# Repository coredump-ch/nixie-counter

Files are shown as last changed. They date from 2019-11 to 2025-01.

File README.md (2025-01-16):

# Nixie Counter

## Description / Overview

PCB for a physical "people now present" counter that sends it data directly to
the [SpaceAPI](https://spaceapi.io/).

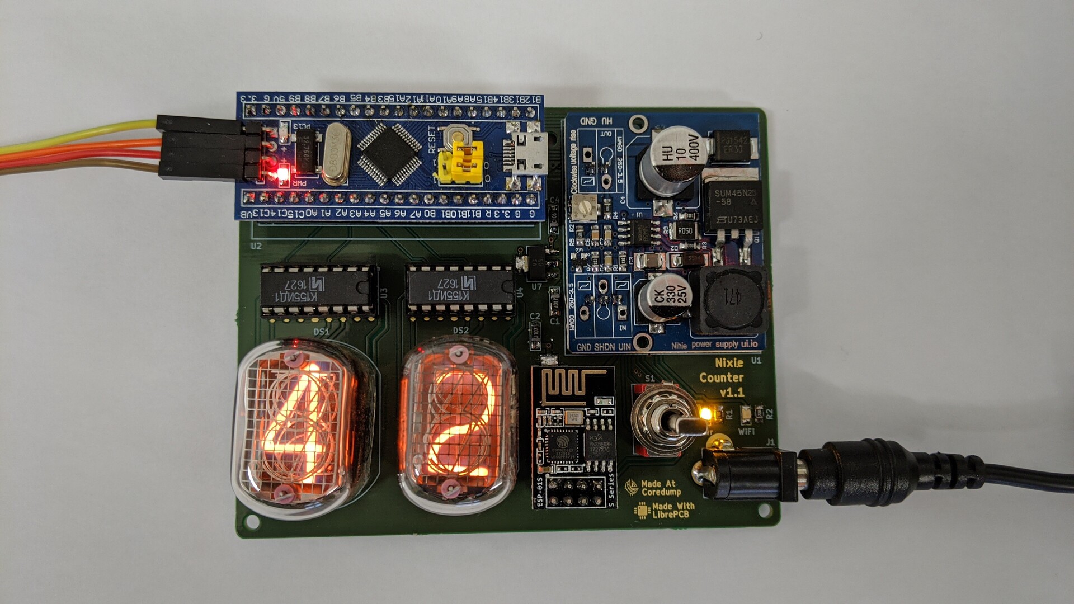
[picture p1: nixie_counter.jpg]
Photo without enclosure


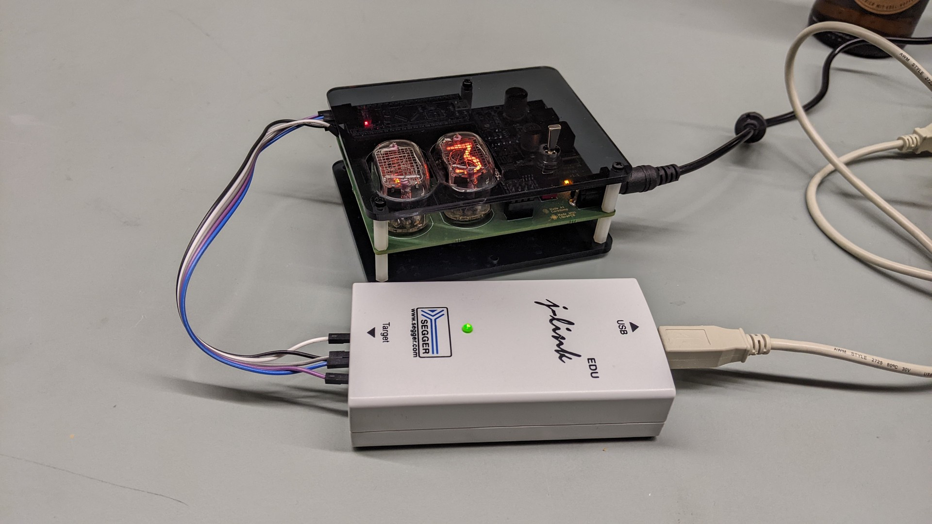
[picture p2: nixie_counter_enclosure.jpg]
Photo with enclosure


**Microcontroller**

The microcontroller is an ESP32C3 based [M5Stack
STAMP-C3U](https://docs.m5stack.com/en/core/stamp_c3u) board. We chose this
because it's quite cheap, has everything built-in that we need and it can run
firmware written in [Rust](https://www.rust-lang.org/).

**Input Methods**

To enter the number of people present, a 2-position momentary toggle switch is
used that can be pushed upwards or downwards.

**Display**

The number of people present is then displayed on two IN-12B nixie tubes. Those
tubes need 150-160 V for turning on, for this we use a [NCH6100HV
module](https://www.nixie.ai/nch6100hv/). The tubes are controlled through two
K155ID1 BCD-to-Decimal drivers. Those need 5V logic levels, so we use a level
shifter between the drivers and the microcontroller.

**Power Supply**

Input power is supplied at 12V. The nixie power supply converts that to ~150V.

An LDOs convert the 12V to 5V, for both the nixie drivers and the ESP32 module.

**Status LEDs**

There's a yellow LED to indicate that the controller has power and runs the
correct firmware, and a green LED to indicate whether the module is connected
to the WiFi or not.

## Functionality

- When starting, the people count will be set to 0
- When pressing the toggle switch up or down, the people count will be modified
  and the nixie tube will show the sent number
- Every minute, the current count will be re-sent to the server (to allow
  server-side timeout implementations)

## PCB

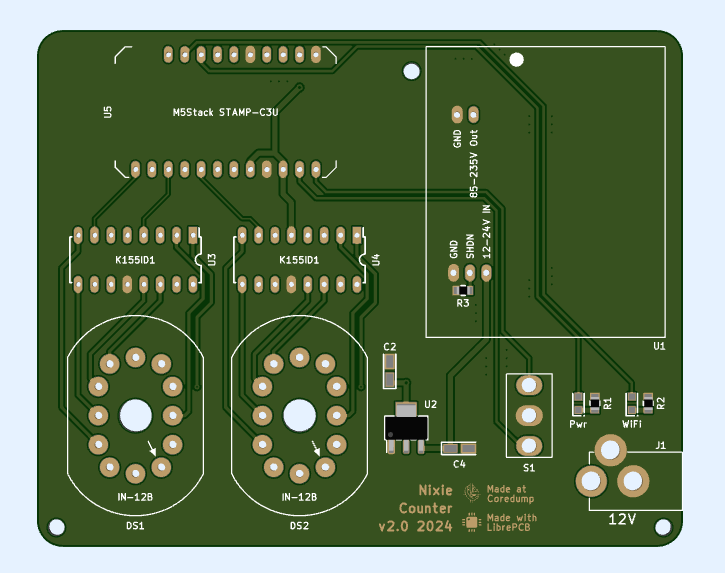
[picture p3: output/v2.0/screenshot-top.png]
Top


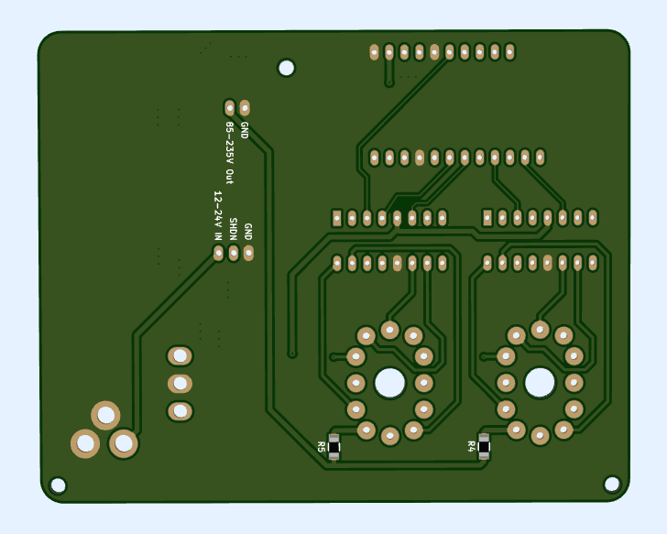
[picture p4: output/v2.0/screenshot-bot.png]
Bottom


For the BOM, see
[`output/v2.0/assembly/Nixie_Counter_v2.0_BOM_Std.csv`](output/v2.0/assembly/Nixie_Counter_v2.0_BOM_Std.csv)
and
[`output/v2.0/assembly/Nixie_Counter_v2.0_BOM_Std.html`](output/v2.0/assembly/Nixie_Counter_v2.0_BOM_Std.html).

## Editing

This is a [LibrePCB](https://librepcb.org) project!

## License

TAPR Open Hardware License, see [LICENSE.txt](LICENSE.txt).

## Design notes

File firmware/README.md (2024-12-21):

# Nixie Counter Firmware

## Prerequisites

- Rust
- Cargo
- espflash
- ldproxy

## Flashing

    export WIFI_SSID=...
    export WIFI_PASS=...
    export SPACEAPI_SENSOR_ENDPOINT=http://example.com/sensors/people_now_present/
    cargo run --release

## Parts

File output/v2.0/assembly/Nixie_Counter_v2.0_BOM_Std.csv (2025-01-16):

Quantity | Designators | Package | SOURCE | ALIEXPRESS | DIGIKEY | Value | MPN | Manufacturer | Value[2] | MPN[2] | Manufacturer[2]
1 | C2 | CAPPM320X160X180L80X120 |  |  | 478-8152-1-ND | 100μF | F930J107KAA | AVX
1 | C4 | CAPPM320X160X180L80X120 |  |  | 478-8237-1-ND | 10μF | F931C106MAA | AVX
2 | DS1, DS2 | Reflektor / Sovtek IN-12 | Ebay |  |  |  | IN-12B | Reflektor
1 | J1 | Barrel Jack DC-005 |  |  |  | Barrel Jack Center Pos
1 | L1 | LOGO_COREDUMP_3.4mm |  |  |  | Made at Coredump
1 | LED1 | OSRAM_CHIPLED0805_DIFFUSED |  |  | 475-2560-1-ND | Pwr | LY R976-PS-36 | OSRAM
1 | LED2 | OSRAM_CHIPLED0805_DIFFUSED |  |  | 475-1410-1-ND | WiFi | LG R971-KN-1 | OSRAM
1 | R1 | RESC2012 (0805) |  |  | 311-270CRCT-ND | 270Ω | RC0805FR-07270RL | Yageo
1 | R2 | RESC2012 (0805) |  |  | 311-220CRCT-ND | 220Ω | RC0805FR-07220RL | Yageo
1 | R3 | RESC2012 (0805) |  |  | 311-0.0ARCT-ND | 0Ω | RC0805JR-070RL | Yageo
2 | R4, R5 | RESC3216 (1206) |  |  | 311-15.0KFRCT-ND | 15kΩ | RC1206FR-0715KL | Yageo
1 | S1 | Salecom T8014A-UHBx | AliExpress | https://aliexpress.com/item/33033590581.html |  |  | T8014A-UHBx | Salecom
1 | U1 | NCH6100HV | AliExpress | https://aliexpress.com/item/32834903717.html |  | NCH6100HV Power Supply
1 | U2 | SOT223-4P230_700X180L175X75T175X300 |  |  | 296-21114-1-ND | LDO 5V | TLV1117-50CDCYR | Texas Instruments
2 | U3, U4 | DIP762W55P254L2007H533Q16 | Ebay |  |  |  | К155ИД1 | Integral
1 | U5 | M5STACK_STAMP_C3U |  |  |  |  | K122 | M5Stack |  | C122-B | M5Stack

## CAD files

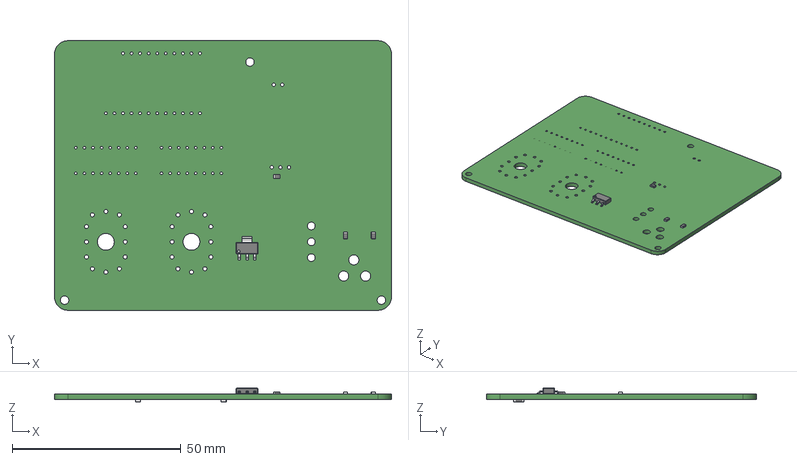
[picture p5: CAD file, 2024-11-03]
output/v2.0/Nixie_Counter_v2.0.step
100.0 x 80.0 x 4.10 mm
PCB:1
R1:1
R2:1
R3:1
R4:1
R5:1
U2:1

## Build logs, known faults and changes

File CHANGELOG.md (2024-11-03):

# Hardware Changelog

## v2.0

- Switch to ESP32C3 based board, redesign whole PCB
- Remove ESP8266 module (not needed anymore)
- Remove 3.3V LDO (not needed anymore)
- Add text and frames to schematic

## v1.1

- Add tube anode resistor
- Flip nixie tube footprint (it was on the wrong side)
- Rounded corners
- Improve label placement

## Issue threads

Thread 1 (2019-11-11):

Power supply for blue pill

dbrgn, 2019-11-11:
It would be nice if we could avoid having to power the blue pill through USB.

Maybe re-use the adjustable regulator board from the iC880A backplane project.

dbrgn, 2019-11-15:
Argh, it gets a bit complicated.

I first added a 3.3V 800mA LDO for the Blue Pill and the ESP8266, but then realized that the 5V output of the Blue Pill (required for the logic level of the BCD chips) does not work when not plugged in via USB.

I then replaced the LDO with a 5V version, in order to power the Blue Pill through that LDO directly. The issue now is that the regulator on the Blue Pill will only output 300 mA. For the ESP8266, it is recommended to be able to provide at least 300 mA continuously, but it would have to share that with the Blue Pill.

It's all less than ideal... We could of course add two LDOs, one for 5V and one for 3.3V, both powered by the 12V PSU.

Alternatively, we drop the blue pill completely (it *is* overkill) and use something like an ESP8266 or ESP32, but with the firmware written in C instead of Rust. This would probably be the most pragmatic approach.

What do you think, @rnestler?

dbrgn, 2019-11-21:
For the record, I'll simply add a second LDO.

Closed 2019-11-23.

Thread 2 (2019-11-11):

Add Logos to board

dbrgn, 2019-11-11:

dbrgn, 2019-11-24:
LibrePCB logo missing, see #7.

Closed 2019-11-24.

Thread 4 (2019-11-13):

Add ESP8266

dbrgn, 2019-11-13:

rnestler, 2019-11-13:
Huh you want an ESP8266 *and* the bluepill?

dbrgn, 2019-11-13:
The blue pill does not have any networking. How do you transmit the data to the internet? :slightly_smiling_face:

(Blue pill, 'cause Rust :crab: I think native ESP8266 support still isn't that good. I'd use the ESP as a serial modem.)

rnestler, 2019-11-13:
Why not just use an nRF module then? https://www.nordicsemi.com/Products/Low-power-short-range-wireless They have good Rust support and have WiFi as well, right?

dbrgn, 2019-11-13:
There are a few WiFi modules with Rust support, but no drivers for the WiFi stack...

Here would be 2 experimental crates for ESP8266 over serial support:

- https://github.com/TheZoq2/esp01-rs
- https://github.com/laanwj/k210-sdk-stuff/tree/master/util/esp8266at

An alternative would be the RTL8710, but I doubt that the software support is better...

Ideally we'd have a native Rust WiFi driver for one of those boards.

Closed 2019-11-23.

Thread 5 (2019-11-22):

Turning on NCH6100HV with Blue Pill

dbrgn, 2019-11-22:
Should the power supply for the nixie tubes be connected to the blue pill so we can turn it on and off with a GPIO?

When pulling SHDN pin high, the power supply turns off.

Rationale: When the power supply is off by default, we can initialize everything (including WiFi) before turning on the tubes.

Requirements: The GPIO pin would need to be high at boot, otherwise this would be of little use.

dbrgn, 2019-11-23:
As far as [I can tell](https://electronics.stackexchange.com/questions/28531/what-is-the-common-pin-configuration-upon-microcontroller-reset) the GPIO pins are configured as inputs after reset, which means that the tube power supply would get power for a few milliseconds before we can turn it off. So this would be of little use if we want to control the power draw when powering on.

While the power supply would run when SHDN is connected directly to GND (or left floating), the tubes are off by default, so I don't think this is a big issue.

Closed 2019-11-23.

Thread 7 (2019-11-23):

Review

dbrgn, 2019-11-23:
@rnestler @ubruhin Does one of you have time to give this board a review? I think it should now be ready for ordering a prototype PCB.

For an overview, see the README file.

ubruhin, 2019-11-24:
I didn't review it in detail, but some mounting holes in the PCB might be nice to have :)

And the "Made With LibrePCB" logo is missing :scream:

dbrgn, 2019-11-24:
Oh, two very good points :smile:

dbrgn, 2019-11-24:
Both fixed.

Closed 2019-11-29.

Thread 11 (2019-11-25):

Increase clearance for 150V traces

dbrgn, 2019-11-25:
0.4 or 0.5mm

dbrgn, 2019-11-26:
Changed to 0.45mm.

Closed 2019-11-26.

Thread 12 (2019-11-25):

Change footprint of toggle switch

dbrgn, 2019-11-25:
Directly solder in the switch. Verify that height is OK.

dbrgn, 2019-11-26:
Should work if we leave 20mm space inside the enclosure!

Closed 2019-11-29.

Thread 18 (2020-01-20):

Add resistor for the Tubes

rnestler, 2020-01-20:
@dbrgn Did you already do this?

dbrgn, 2020-01-20:
Yes, but I haven't pushed it yet. I first want to solder in a resistor manually to test whether it works as intended. If that's the case, I'll probably order new PCBs.

dbrgn, 2020-02-03:
Fixed in 6192590d353f609020a5828986d185787f941594

Closed 2020-02-03.

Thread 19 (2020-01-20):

v1.0 Testing: Verify that nixie tubes work

dbrgn, 2020-01-20:
Main issue found: Missing anode resistor for tubes. #18

dbrgn, 2020-02-03:
Also, the footprint is mirrored (top/down) :man_facepalming:

Closed 2020-02-25.

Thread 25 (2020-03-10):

WiFi

dbrgn, 2020-03-10:
Create a ESP8266 WiFi driver and send counter changes to the SpaceAPI.

Make sure to show/hide the WiFi LED when the connection status changes. Blink it when sending data.

dbrgn, 2023-10-16:
Obsolete. Replace with ESP32 which is much more reliable.

Closed 2023-10-16.

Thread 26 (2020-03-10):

Sleep when idle

dbrgn, 2020-03-10:
Wake up on interrupt.

May have implications on WiFi module (#25).

dbrgn, 2024-12-20:
This should be automatically the case with embassy (see #41).

Closed 2024-12-20.

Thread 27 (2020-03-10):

Create enclosure

dbrgn, 2020-03-10:
Rough idea: Use laser cut acrylic top plate, connected to the PCB using spacers.

I'm not yet sure about the back side yet...

dbrgn, 2023-10-16:
Completed in a0179ab

Closed 2023-10-16.

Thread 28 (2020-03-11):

Expose PB3 (ITM SWO)

dbrgn, 2020-03-11:
Unfortunately, pin PB3 is currently connected to the power LED, even though this pin would be required for logging through ITM.

Free and expose the ITM pin for easier debugging.

dbrgn, 2024-10-27:
Obsolete with ESP32.

Closed 2024-10-27.

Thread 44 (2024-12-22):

NCH6100HV: Larger holes

dbrgn, 2024-12-22:
The holes are too small.

dbrgn, 2024-12-22:
Hmm, holes are already 1mm in the PCB design. Is that not enough?

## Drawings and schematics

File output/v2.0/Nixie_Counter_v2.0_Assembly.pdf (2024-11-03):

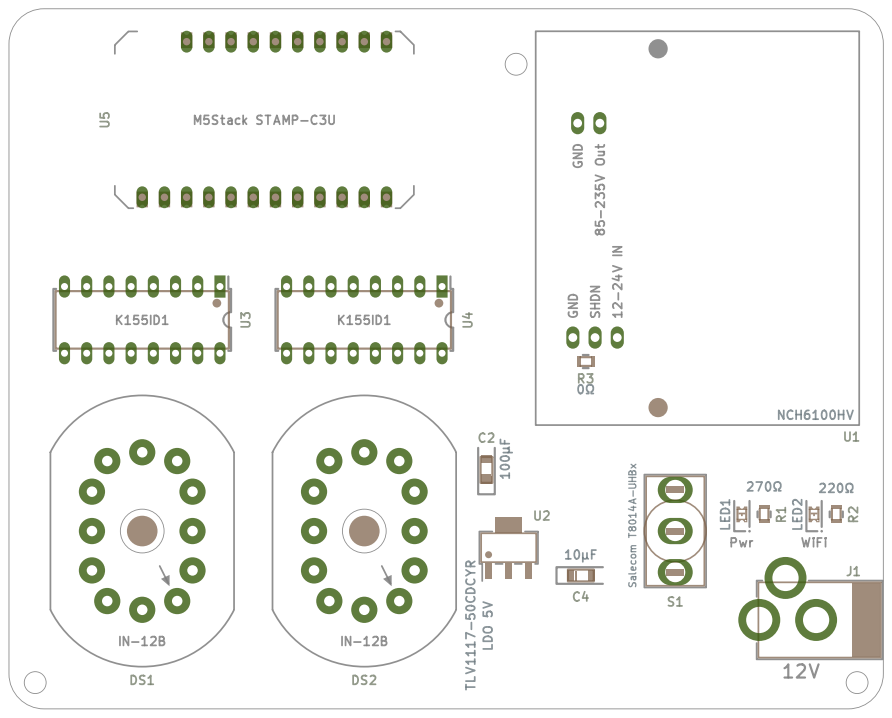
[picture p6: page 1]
85-235V Out; LDO 5V; Salecom T8014A-UHBx

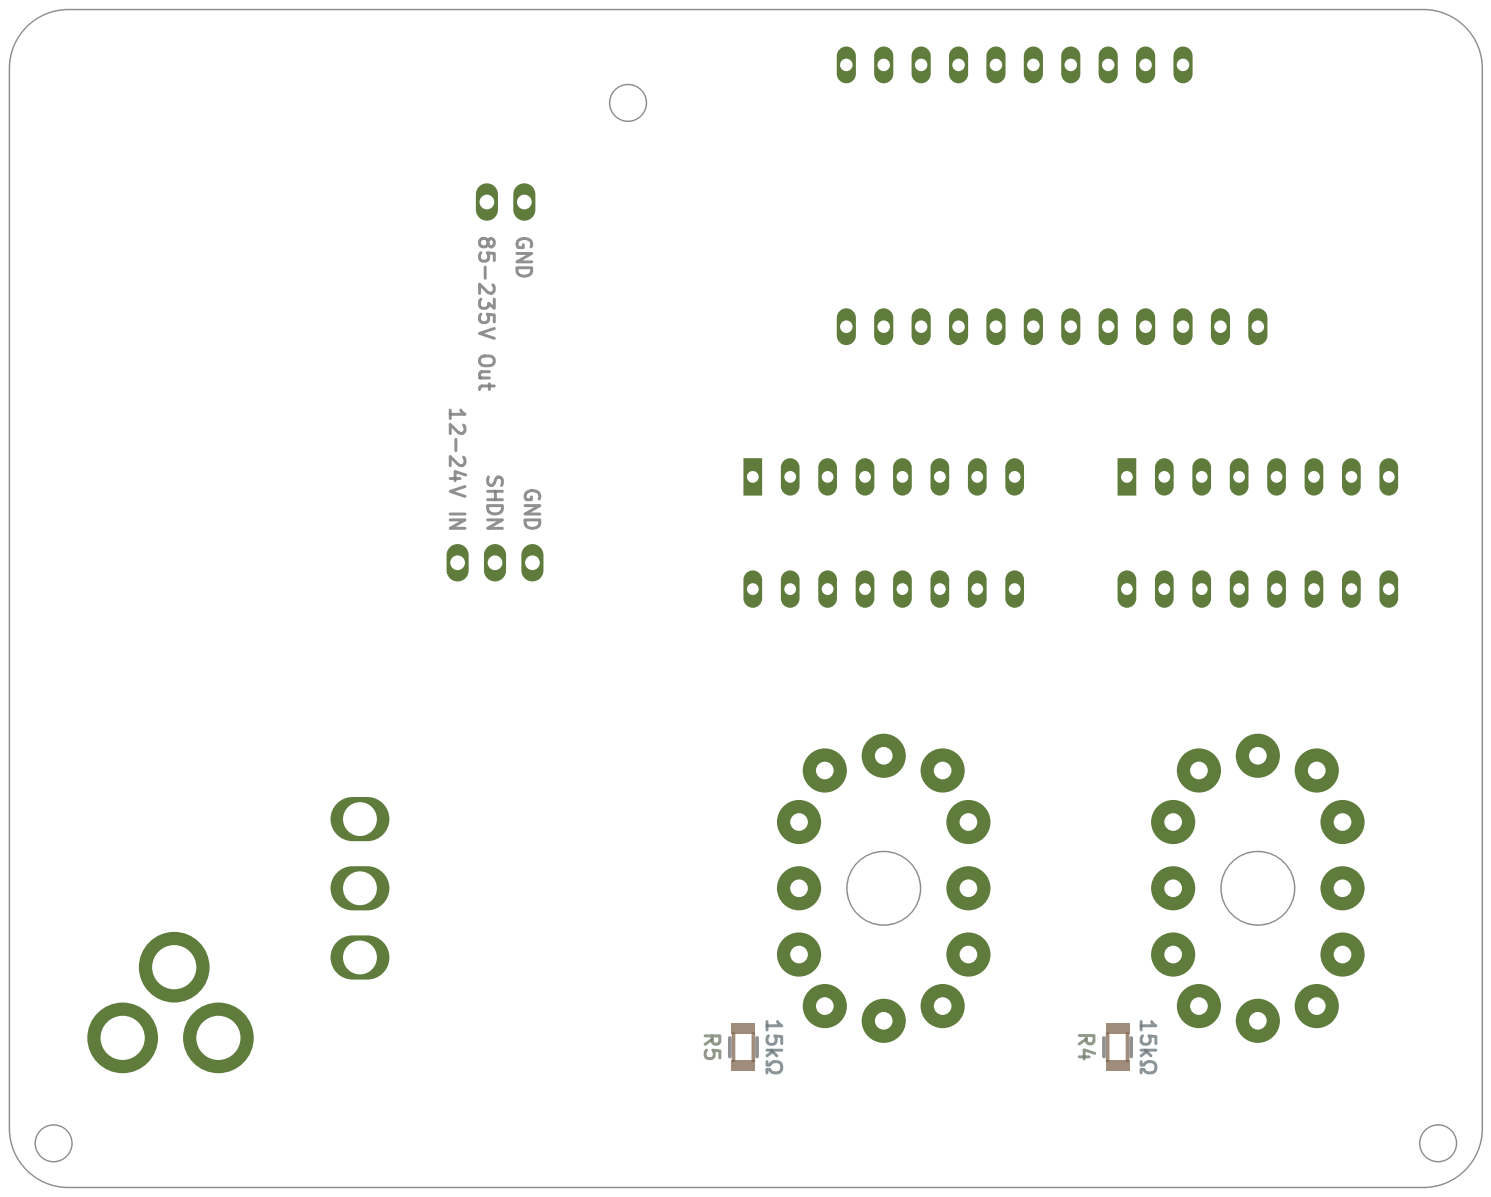
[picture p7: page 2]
85-235V Out

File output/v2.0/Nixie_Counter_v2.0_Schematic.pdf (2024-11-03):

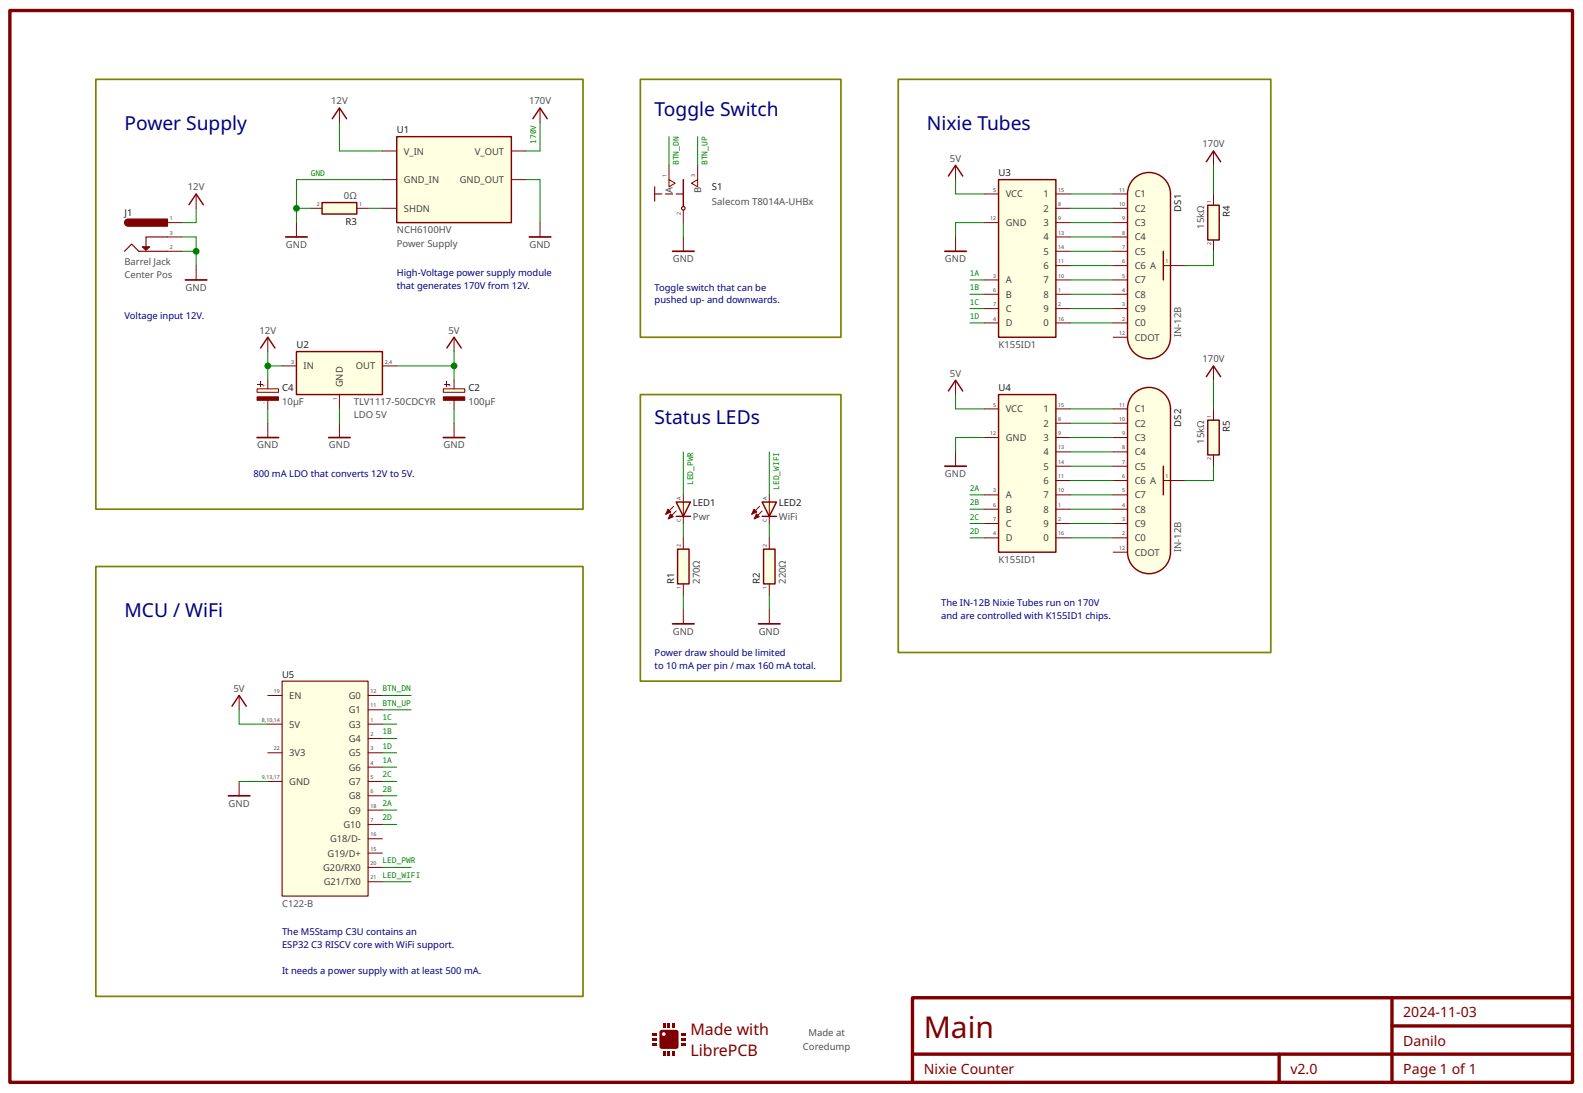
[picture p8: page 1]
GND 1; WiFi LED2; nilo in; V. Nixie; al. MCU / WiFi; The M5Stamp C3U contains an ESP32 C3 RISCV core with WiFi support. It needs a power supply with at least 500 mA.; 2A ED_WIFI

s. Power draw should be limite

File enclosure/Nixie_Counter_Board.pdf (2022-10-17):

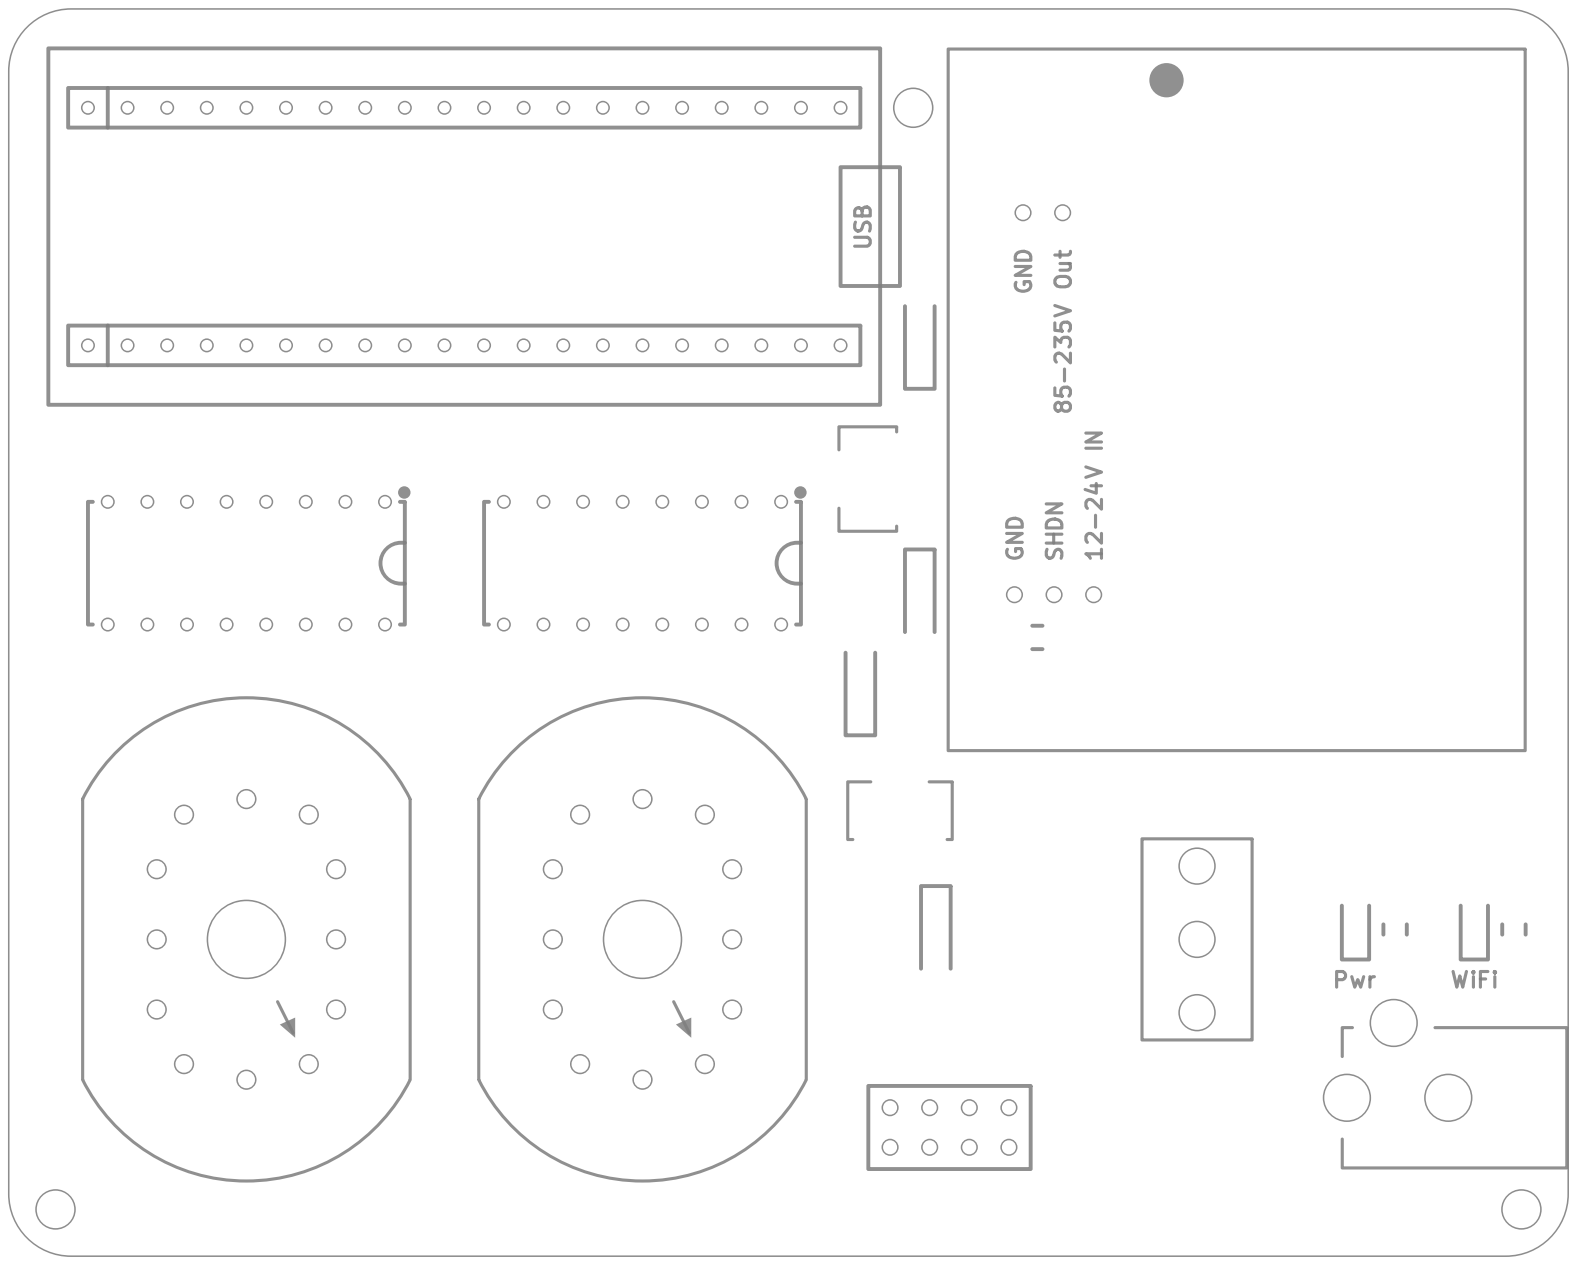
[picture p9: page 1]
85-235V Out

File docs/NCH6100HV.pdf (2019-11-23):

NCH6100HV High Voltage Power Supply v1.0.0 | http://www.nixieclock.org
Designer: Yan Zeyuan. China. | Email:yanzeyuan@163.com | Website：www.nixieclock.org | 1 / 4

# NCH6100HV High Voltage DC Power Supply

Designer： | Yan Zeyuan | Version 1.0.0
Website： | http://www.nixieclock.org
E-mail： | yanzeyuan@163.com

# Attention

### ◇ Attention： High voltage circuit on the board, do not touch the circuit board and

| components if it’s working.
◇ Warning: | Overload prohibited (Input voltage/output current out of range).
◇ Warning: | Exposing outdoor prohibited, using in moist or raining place prohibited.
◇ Warning: | Board will generate heat, be sure the board is well heat dissipation.

# Features

### NCH6100HV high voltage power supply module is miniature step-up DC-DC converter with high

efficiency and low heat operating from 12 to 24VDC input, with an output of 85 to 235VDC set by a precise potentiometer. Designed for Nixie tube, VFD tube, Magic eye etc. Shutdown mode are controlled via SHDN logic input. PCB terminals and pin headers are optional.

# Technical specifications

### Electronic Specifications

Specification | Symbol | Min | Typ | Max | Units
Input voltage | VIN | 10.00 | 12.00 | 24.00 | Volts
Output voltage (Io = 10mA) | VOUT | 85.00 | --- | 235.00 | Volts
Output current (VIN = 12V VOUT = 90V) | IOUT | 0 | 45 | 95 | mAmps
Output current (VIN = 12V VOUT = 170V) | | 0 | 35 | 55 | mAmps
Output current (VIN = 12V VOUT = 220V) | | 0 | 24 | 35 | mAmps
SHDN input voltage | VSHDN | 1.2 | --- | VIN | Volts
SHDN input current | ISHDN | --- | --- | 2 | mAmps
Shutdown current (VIN = 12V VOUT = 170V) | IOFF | --- | 15 | --- | mAmps
Efficiency (VIN = 12-18VDC, 50%-80% rated load) | Efficiency | --- | 80 | --- | %

Notes:

1. Ground or float SHDN to enable switcher, must be tied to VIN to turn off switcher.
2. No input reverse polarity protection is provided.

Designer: Yan Zeyuan. China. | Email:yanzeyuan@163.com | Website：www.nixieclock.org | 2 / 4

### Efficiency curve ( VIN = DC 12V )

### Typical connection

95

90

85

80

75

70

Efficiency - %

0 | 40 | 60 | 80 | 100
Ouput current - mA

Vo = 90v

EFFICIENCY
vs
OUTPUT CURRENT

20

95

90

85

80

75

70

Efficiency - %

0 | 10 | 20 | 30 | 40 | 50 | 60 | 70
Ouput current - mA

Vo = 170v

EFFICIENCY
vs
OUTPUT CURRENT

95

90

85

80

75

70

Efficiency - %

0 | 10 | 20 | 30 | 40
Ouput current - mA

Vo = 220v

EFFICIENCY
vs
OUTPUT CURRENT

DC 12v - 24v IN

GND | GND

SHDN

VIN

GND

HV | DC 85v - 235v OUT

GND

NCH6100HV

DC 12v - 24v IN

GND | GND

SHDN
VIN

GND

HV | DC 85v - 235v OUT

GND

NCH6100HV

DC 12v - 24v IN

GND | GND

SHDN

VIN

GND

HV | OUT OFF

GND

NCH6100HV

DC 12v - 24v IN

GND | GND

SHDN
VIN

GND

HV | OUT ON/OFF

GND

NCH6100HV

I/O | MCU | GND | GND

Always on - float SHDN

ON with connect SHDN to GND

Off with connect SHDN to VIN

MCU control
SHDN High - Off
SHDN Low - On

Note:

### 1. Recommended input capacitor if the module is located far

from the power.

### 2. Module will generate heat, be sure the board is well heat

dissipation.

### Adjust output voltage

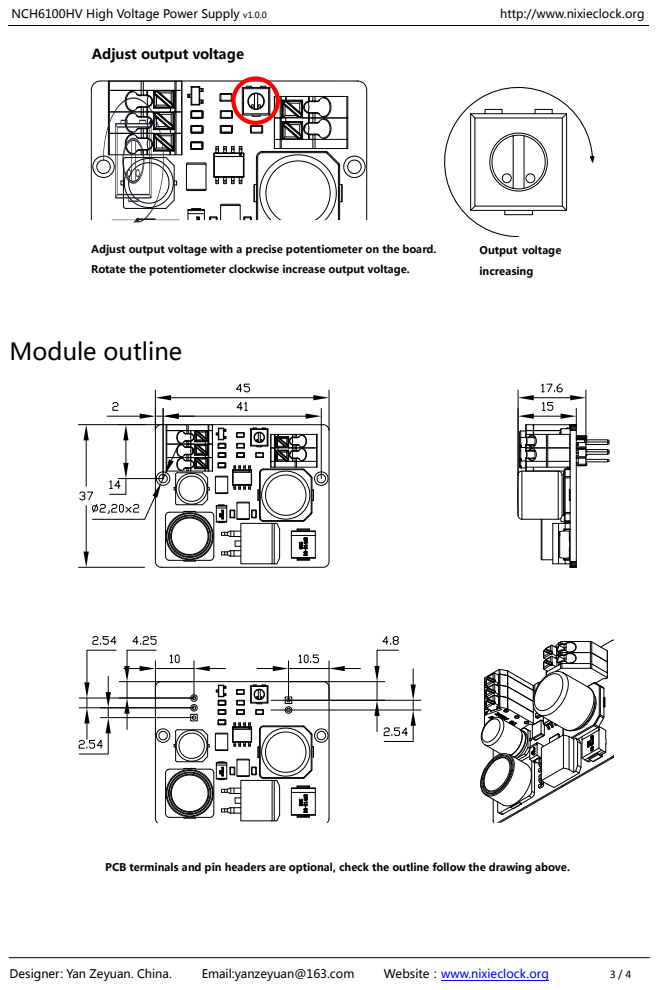
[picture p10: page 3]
Designer: Yan Zeyuan. China.; Email:yanzeyuan@163.com; Website：www.nixieclock.org; Module outline; Output voltage; increasing

Adjust output voltage with a precise potentiometer on the board.
Rotate the potentiometer clockwise increase output voltage.

PCB terminals and pin headers are optional, check the outline follow the drawing above.

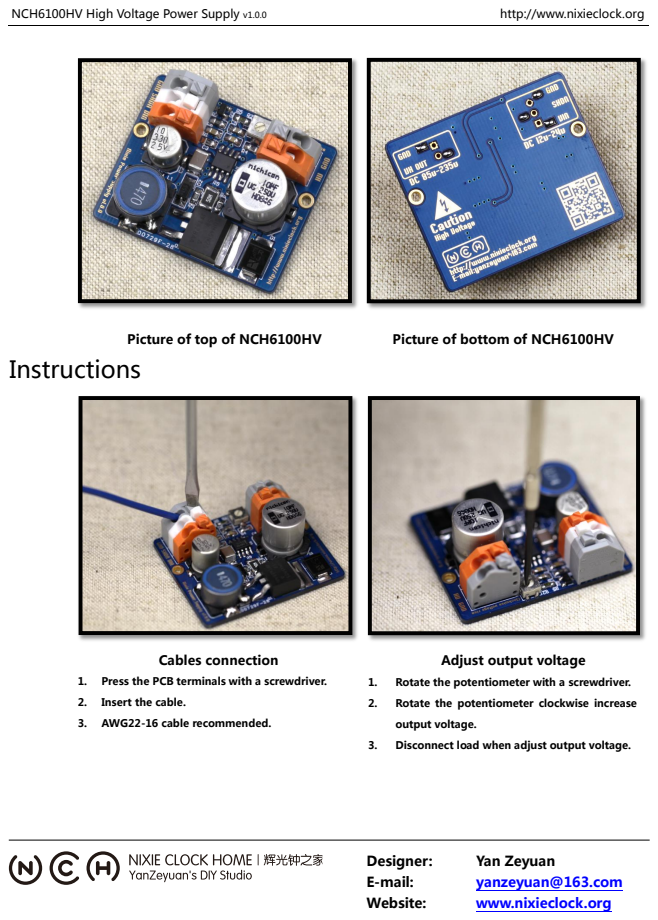
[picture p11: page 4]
Designer: Yan Zeyuan. China.; Email:yanzeyuan@163.com; Website：www.nixieclock.org; Picture of top of NCH6100HV; Picture of bottom of NCH6100HV; Instructions; Designer:; Yan Zeyuan; E-mail:; yanzeyuan@163.com; Website:; www.nixieclock.org; Cables connection

Adjust output voltage

1. Press the PCB terminals with a screwdriver.
2. Insert the cable.
3. AWG22-16 cable recommended.

1. Rotate the potentiometer with a screwdriver.
2. Rotate the potentiometer clockwise increase
output voltage.
3. Disconnect load when adjust output voltage.

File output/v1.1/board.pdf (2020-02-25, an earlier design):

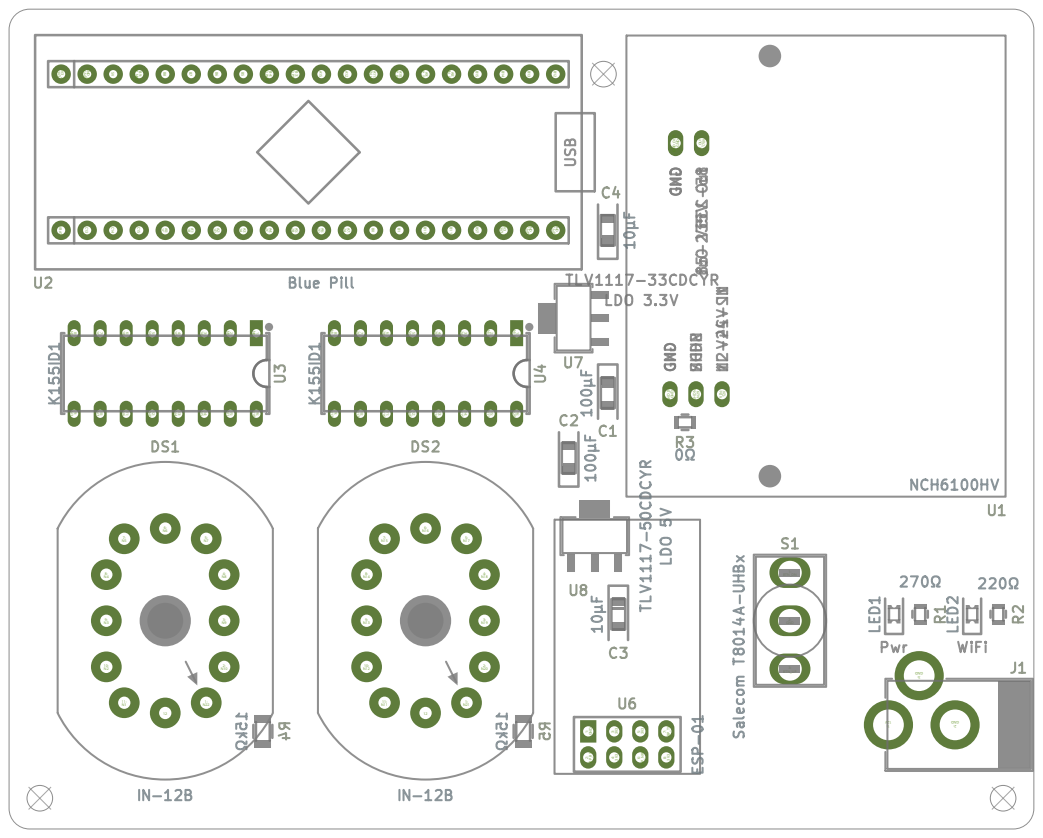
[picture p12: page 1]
12: GND; GND_1: GND; B3: LED_PWR; A11: BTN_UP; B4: LED_WIFI; GND_2: GND; A8: BTN_DN; B9: ESP_NRST; GND_3: GND; 3: BTN_UP; 1: BTN_DN; 2: GND

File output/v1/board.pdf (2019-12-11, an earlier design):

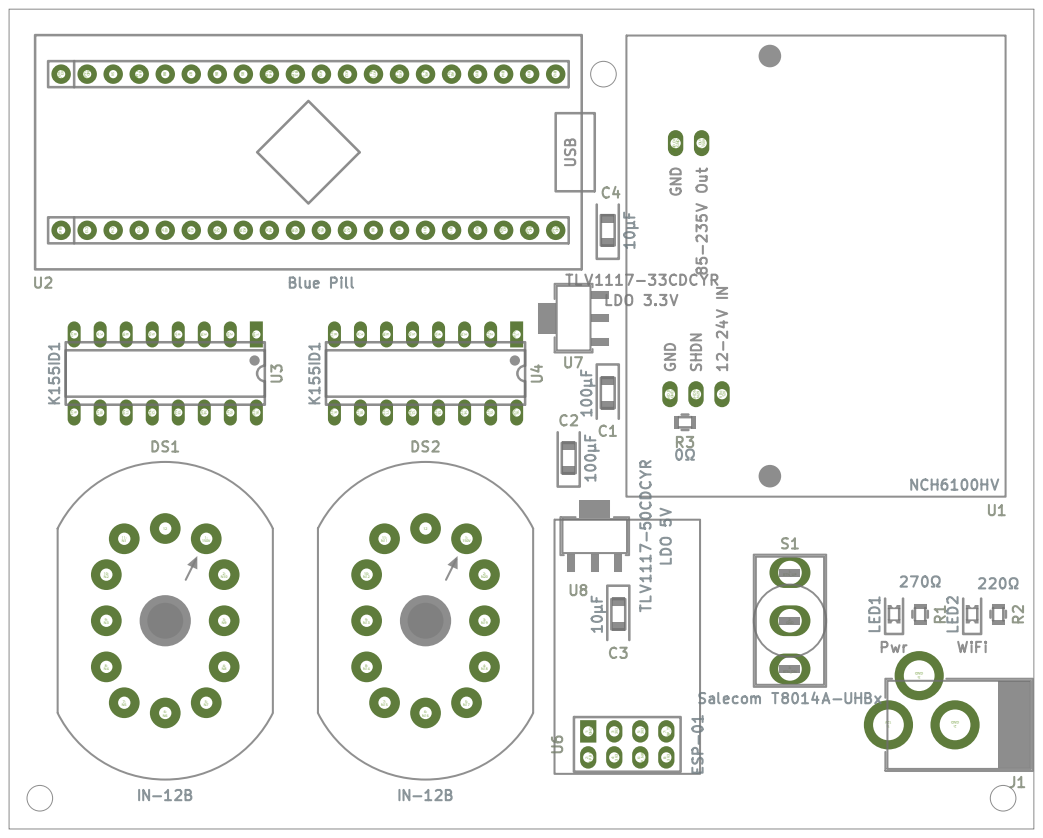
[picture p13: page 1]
12: GND; GND_1: GND; B3: LED_PWR; A11: BTN_DN; B4: LED_WIFI; GND_2: GND; A8: BTN_UP; B9: ESP_NRST; GND_3: GND; 3: BTN_DN; 1: BTN_UP; 2: GND

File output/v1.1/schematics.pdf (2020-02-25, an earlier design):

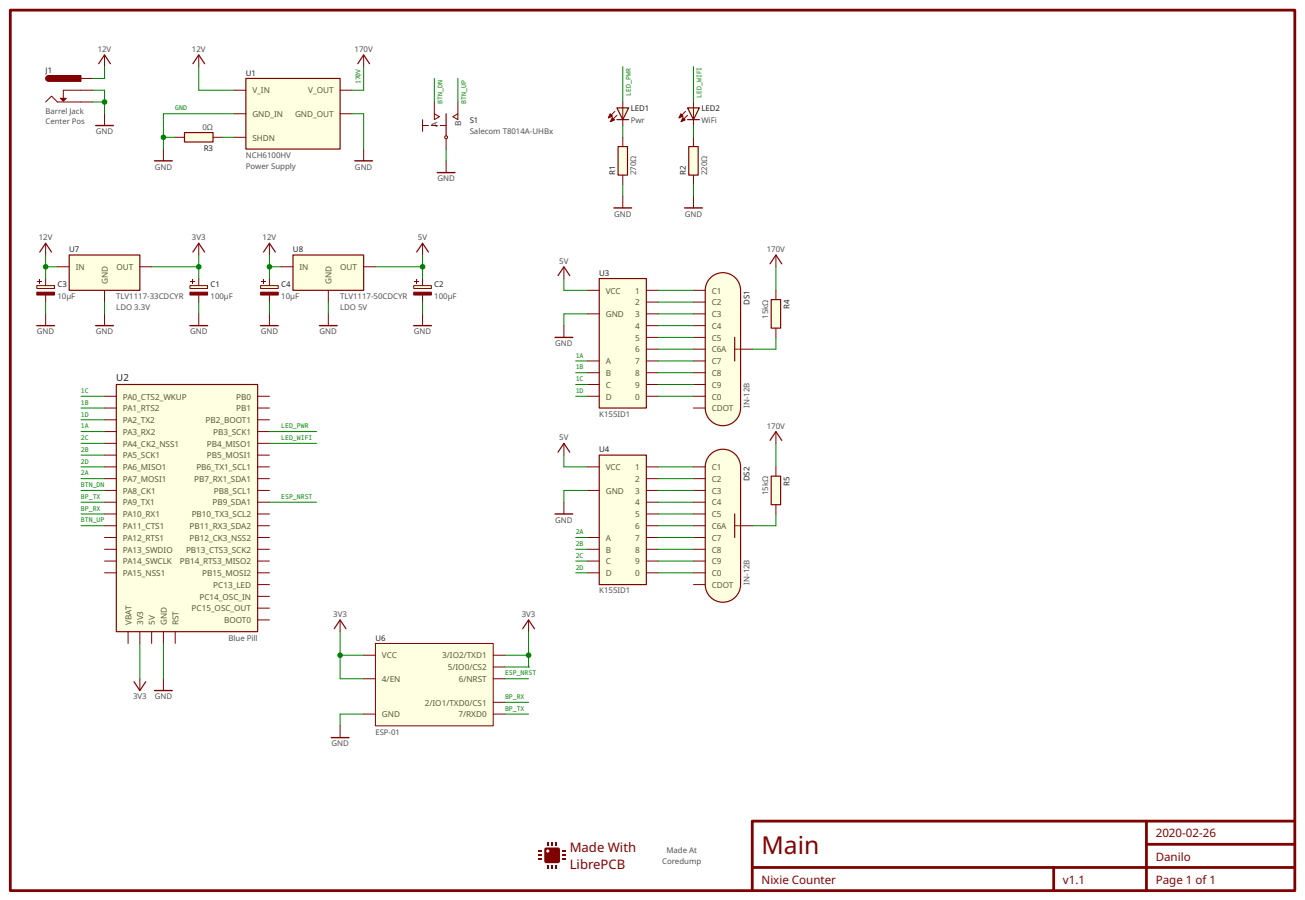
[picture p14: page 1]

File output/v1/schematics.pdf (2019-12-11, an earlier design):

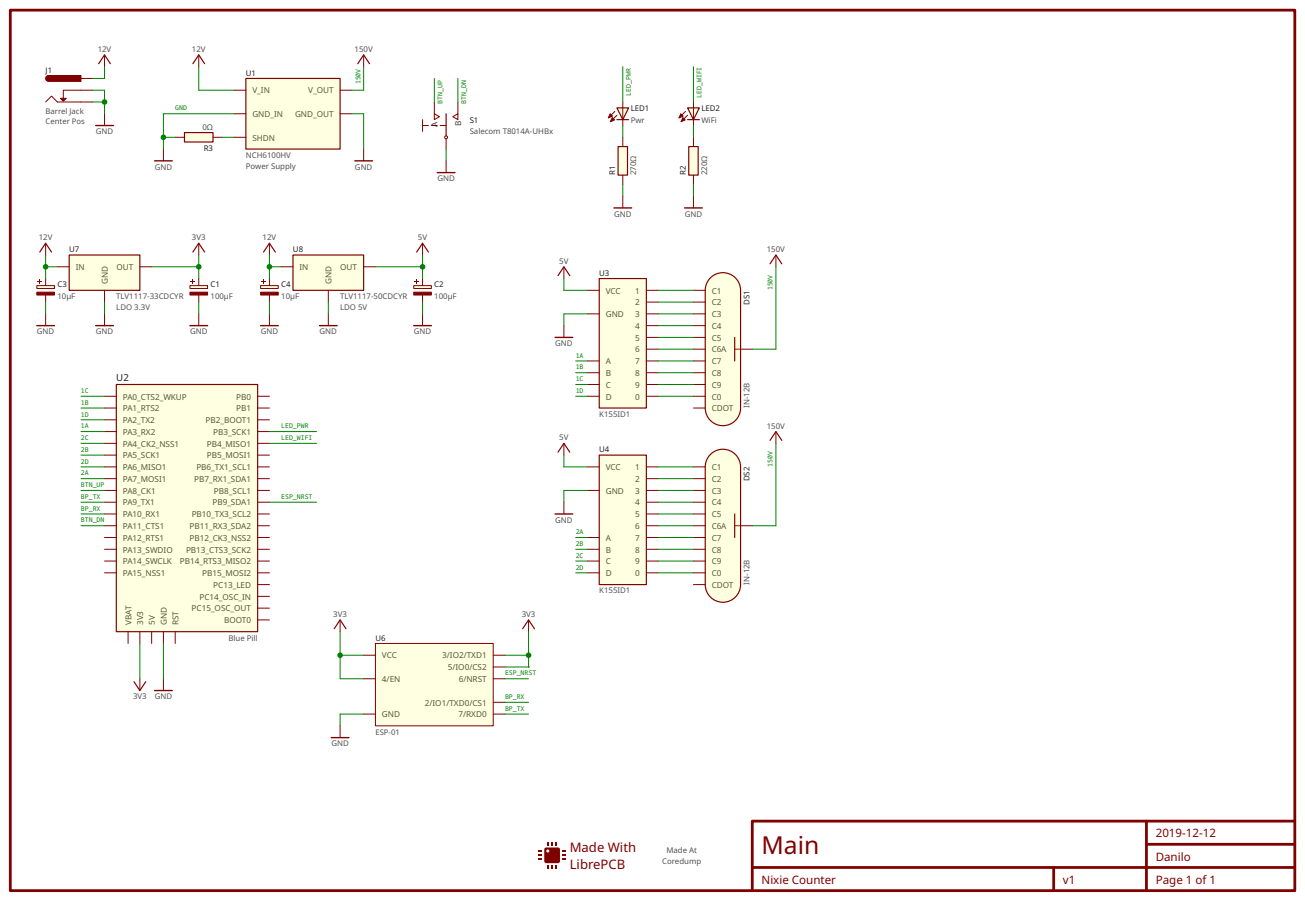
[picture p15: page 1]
VBAT PA

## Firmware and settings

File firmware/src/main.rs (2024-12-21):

#![no_std]
#![no_main]

use core::{fmt::Write, str::FromStr};

use embassy_executor::Spawner;
use embassy_futures::select::{select, Either};
use embassy_net::{
    dns::DnsSocket,
    tcp::client::{TcpClient, TcpClientState},
    DhcpConfig, Stack, StackResources,
};
use embassy_sync::{
    blocking_mutex::raw::NoopRawMutex,
    channel::{Channel, Receiver, Sender},
};
use embassy_time::{Duration, Ticker, Timer};
use esp_alloc as _;
use esp_backtrace as _;
use esp_hal::{
    gpio::{Level, Output},
    timer::timg::TimerGroup,
};
use esp_println::println;
use esp_wifi::{
    wifi::{
        ClientConfiguration, Configuration, WifiController, WifiDevice, WifiEvent, WifiStaDevice,
        WifiState,
    },
    EspWifiController,
};
use reqwless::{
    client::HttpClient,
    request::{Method, RequestBuilder},
    response::Status,
};
use toggle_switch::Direction;

mod nixie;
mod toggle_switch;

use crate::{
    nixie::{NixieTube, NixieTubePair},
    toggle_switch::ToggleSwitch,
};

const VERSION: &str = env!("CARGO_PKG_VERSION");

const WIFI_SSID: &str = env!("WIFI_SSID");
const WIFI_PASS: &str = env!("WIFI_PASS");
const SPACEAPI_SENSOR_ENDPOINT: &str = env!("SPACEAPI_SENSOR_ENDPOINT");

const DHCP_HOSTNAME: &str = "Nixie Counter";
const PERIODIC_COUNT_UPDATE_INTERVAL: Duration = Duration::from_secs(60);

type EspWifiDevice<'a> = WifiDevice<'a, WifiStaDevice>;
type EspTcpClient<'a> = TcpClient<'a, EspWifiDevice<'a>, 1>;
type EspDnsSocket<'a> = DnsSocket<'a, EspWifiDevice<'a>>;
type EspHttpClient<'a> = HttpClient<'a, EspTcpClient<'a>, EspDnsSocket<'a>>;

// Note: When you are okay with using a nightly compiler it's better to
// use https://docs.rs/static_cell/2.1.0/static_cell/macro.make_static.html
macro_rules! mk_static {
    ($t:ty,$val:expr) => {{
        static STATIC_CELL: static_cell::StaticCell<$t> = static_cell::StaticCell::new();
        #[deny(unused_attributes)]
        let x = STATIC_CELL.uninit().write(($val));
        x
    }};
}

#[esp_hal_embassy::main]
async fn main(spawner: Spawner) {
    // Initialize 72 KiB heap for alloc
    esp_alloc::heap_allocator!(72 * 1024);

    // Initialize logging
    println!("--- start of main() ---");
    esp_println::logger::init_logger(log::LevelFilter::Debug);

    // Initialize peripherals
    let peripherals = esp_hal::init(esp_hal::Config::default());
    let mut rng = esp_hal::rng::Rng::new(peripherals.RNG);

    // Initialize timer
    let timg0 = TimerGroup::new(peripherals.TIMG0);
    esp_hal_embassy::init(timg0.timer0);

    log::info!("Starting nixie firmware v{VERSION}...");

    // Set up toggle switch
    let mut toggle_switch = ToggleSwitch::new(peripherals.GPIO1, peripherals.GPIO0);

    // Set up LEDs
    let _led_pwr = Output::new(peripherals.GPIO20, Level::High);
    let led_wifi = Output::new(peripherals.GPIO21, Level::Low);

    // Initialize tubes
    let mut tubes = NixieTubePair::new(
        NixieTube {
            pin_a: Output::new(peripherals.GPIO6, Level::Low),
            pin_b: Output::new(peripherals.GPIO4, Level::Low),
            pin_c: Output::new(peripherals.GPIO3, Level::Low),
            pin_d: Output::new(peripherals.GPIO5, Level::Low),
        },
        NixieTube {
            pin_a: Output::new(peripherals.GPIO9, Level::Low),
            pin_b: Output::new(peripherals.GPIO8, Level::Low),
            pin_c: Output::new(peripherals.GPIO7, Level::Low),
            pin_d: Output::new(peripherals.GPIO10, Level::Low),
        },
    );
    tubes.selftest(Duration::from_millis(100)).await;

    // Initialize WiFi
    let timg1 = TimerGroup::new(peripherals.TIMG1);
    let wifi_init = &*mk_static!(
        EspWifiController<'static>,
        esp_wifi::init(timg1.timer0, rng, peripherals.RADIO_CLK,).expect("Failed to init esp_wifi")
    );
    let (wifi_interface, wifi_controller) =
        esp_wifi::wifi::new_with_mode(wifi_init, peripherals.WIFI, WifiStaDevice).unwrap();
    let wifi_config = ClientConfiguration {
        ssid: WIFI_SSID.try_into().unwrap(),
        password: WIFI_PASS.try_into().unwrap(),
        ..Default::default()
    };

    // Init network stack
    let dhcp_config = {
        let mut config = DhcpConfig::default();
        config.hostname = Some(
            heapless::String::from_str(DHCP_HOSTNAME)
                .expect("Failed to construct heapless string for DHCP hostname"),
        );
        config
    };
    let config = embassy_net::Config::dhcpv4(dhcp_config);
    let seed: u64 = rng.random().into();
    log::debug!("Network stack seed: {seed}");
    let stack = &*mk_static!(
        Stack<WifiDevice<'_, WifiStaDevice>>,
        Stack::new(
            wifi_interface,
            config,
            mk_static!(StackResources<3>, StackResources::<3>::new()),
            seed
        )
    );

    // Spawn LED control task
    let led_control_channel = mk_static!(
        Channel::<NoopRawMutex, LedControlCommand, 3>,
        Channel::<NoopRawMutex, LedControlCommand, 3>::new()
    );
    spawner.must_spawn(led_control_task(led_wifi, led_control_channel.receiver()));

    // Spawn connection tasks
    spawner.must_spawn(connection(
        wifi_controller,
        wifi_config,
        led_control_channel.sender(),
    ));
    spawner.must_spawn(net_task(stack));

    // Wait for link
    loop {
        if stack.is_link_up() {
            break;
        }
        Timer::after(Duration::from_millis(200)).await;
    }

    // Wait for IP
    log::info!("Waiting to get IP address...");
    loop {
        if let Some(config) = stack.config_v4() {
            log::info!("Got IP: {}", config.address);
            break;
        }
        Timer::after(Duration::from_millis(200)).await;
    }

    // Create HTTP client (without TLS support for now)
    let client_state = &*mk_static!(
        TcpClientState<1, 1024, 1024>,
        TcpClientState::<1, 1024, 1024>::new()
    );
    let tcp_client = &*mk_static!(
        TcpClient<'static, EspWifiDevice<'static>, 1>,
        TcpClient::new(stack, client_state)
    );
    let dns = &*mk_static!(EspDnsSocket<'_>, DnsSocket::new(stack));
    let mut http_client = HttpClient::new(tcp_client, dns);

    // Send initial count
    if let Err(e) = update_people_now_present(&mut http_client, 0).await {
        log::warn!("Failed to initialize SpaceAPI endpoint count: {}", e);
    }

    // Periodic update timer
    let mut periodic_update_interval = Ticker::every(PERIODIC_COUNT_UPDATE_INTERVAL);

    // Main loop
    log::info!("Starting main loop");
    let mut count = 0u8;
    loop {
        // Wait for event: Either timer or button press
        let direction = match select(
            periodic_update_interval.next(),
            toggle_switch.wait_for_press(),
        )
        .await
        {
            Either::First(()) => {
                // Periodic count update
                if let Err(e) = update_people_now_present(&mut http_client, count).await {
                    log::warn!("Failed to refresh SpaceAPI endpoint count: {}", e);
                }
                continue;
            }
            Either::Second(direction) => {
                // Toggle switch pressed, carry on with processing
                direction
            }
        };

        // Wait for toggle switch press
        log::info!("Pressed {:?}", direction);

        // Debouncing
        Timer::after(Duration::from_millis(250)).await;

        // Update SpaceAPI
        let new_count = match direction {
            Direction::Up => count.saturating_add(1),
            Direction::Down => count.saturating_sub(1),
        };
        match update_people_now_present(&mut http_client, new_count).await {
            Ok(()) => {
                // Success, update nixie tubes
                tubes.show(new_count.min(99));
                count = new_count
            }
            Err(e) => {
                // Failed to update SpaceAPI
                log::error!("Failed to update SpaceAPI endpoint: {}", e)
            }
        }

        // Wait for toggle switch release
        toggle_switch.wait_for_release().await;
    }
}

enum LedControlCommand {
    TurnOn,
    TurnOff,
    Blink { delay: Duration },
}

/// Task: Control WiFi LEDs
#[embassy_executor::task]
async fn led_control_task(
    mut led: Output<'static>,
    command_receiver: Receiver<'static, NoopRawMutex, LedControlCommand, 3>,
) {
    log::info!("Start LED connection task");
    led.set_low();
    loop {
        match command_receiver.receive().await {
            LedControlCommand::TurnOn => led.set_high(),
            LedControlCommand::TurnOff => led.set_low(),
            LedControlCommand::Blink { delay } => 'blink: loop {
                led.toggle();
                if command_receiver.is_empty() {
                    // No new command arrives, keep on blinking
                    Timer::after(delay).await;
                } else {
                    // Otherwise, stop and process the command
                    break 'blink;
                }
            },
        }
    }
}

/// Task: Ensure WiFi connection
#[embassy_executor::task]
async fn connection(
    mut controller: WifiController<'static>,
    config: ClientConfiguration,
    led_command_sender: Sender<'static, NoopRawMutex, LedControlCommand, 3>,
) {
    log::info!("Start connection task");
    let mut previously_connected = false;
    loop {
        // When currently connected, wait until we're no longer connected
        #[allow(clippy::single_match)]
        match esp_wifi::wifi::wifi_state() {
            WifiState::StaConnected => {
                controller.wait_for_event(WifiEvent::StaDisconnected).await;
                led_command_sender.send(LedControlCommand::TurnOff).await;
                if previously_connected {
                    log::info!("WiFi connection lost");
                }
                Timer::after(Duration::from_millis(5000)).await;
            }
            _ => {}
        }

        // Blink LED to indicate connecting status
        led_command_sender
            .send(LedControlCommand::Blink {
                delay: Duration::from_millis(250),
            })
            .await;

        // Start WiFi
        if !matches!(controller.is_started(), Ok(true)) {
            let client_config = Configuration::Client(config.clone());
            controller.set_configuration(&client_config).unwrap();
            log::info!("Starting WiFi");
            controller.start_async().await.unwrap();
            log::info!("WiFi started!");
        }

        // Connect WiFi
        log::info!("About to connect to WiFi \"{}\"...", config.ssid);
        match controller.connect_async().await {
            Ok(_) => {
                log::info!("WiFi \"{}\" connected!", config.ssid);
                led_command_sender.send(LedControlCommand::TurnOn).await;
                previously_connected = true;
            }
            Err(e) => {
                log::info!("Failed to connect to WiFi: {e:?}");
                Timer::after(Duration::from_millis(2000)).await
            }
        }
    }
}

/// Task: Run network stack
#[embassy_executor::task]
async fn net_task(stack: &'static Stack<EspWifiDevice<'static>>) {
    stack.run().await
}

/// Update the "people now present" sensor through HTTP.
async fn update_people_now_present<'a>(
    client: &mut EspHttpClient<'a>,
    people_count: u8,
) -> anyhow::Result<()> {
    // Prepare URL and payload
    let url = SPACEAPI_SENSOR_ENDPOINT;
    let mut payload_string = heapless::String::<9>::new();
    write!(payload_string, "value={people_count}")?;
    let payload = payload_string.as_bytes();

    // Send request
    let mut rx_buf = [0; 4096];
    let request_handle = match client.request(Method::PUT, url).await {
        Ok(handle) => handle,
        Err(e) => {
            log::error!("Could not create HTTP request handle: {:?}", e);
            anyhow::bail!("HTTP request failed");
        }
    };
    let mut request = request_handle
        .headers(&[("content-type", "application/x-www-form-urlencoded")])
        .body(payload);
    log::info!("-> PUT {}", url);
    let response = match request.send(&mut rx_buf).await {
        Ok(resp) => resp,
        Err(e) => {
            log::error!("HTTP request error: {:?}", e);
            anyhow::bail!("HTTP request failed");
        }
    };

    // Process response
    log::info!("<- HTTP {}", response.status.0);
    if response.status == Status::NoContent {
        log::info!("Successfully set people now present count to {people_count}");
        Ok(())
    } else {
        anyhow::bail!("Received unexpected HTTP status code when sending status update")
    }
}

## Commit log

2019-11-09 Update toggle switch, start routing board
2019-11-11 Continue routing, add barrel jack connector
2019-11-11 Add DC barrel jack to board
2019-11-14 Add ESP8266 to schematics (#4)
2019-11-18 Choose LDO filter caps (#1)
2019-11-23 Update nixie tube library elements
2019-11-23 Add status LEDs (#6)
2019-11-23 README: Add section about status LEDs
2019-11-24 Add LibrePCB logo and mounting holes (#8, #2)
2019-11-25 Connect GND and GND_SUPPLY (#9)
2019-11-26 Fix top mounting hole x-alignment (#13)
2019-11-26 Improve clearance around 150V trace (#11)
2019-11-26 Trace simplifications
2019-11-29 Change footprint of toggle switch (#12)
2019-11-29 Fix silkscreen alignment
2019-11-29 Version 1
    [Nixie_Counter_BOM.csv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]
2019-12-11 Generate v1 fabrication data
    [BOM.csv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]
2019-12-12 BOM: Use comma as separator, remove logos
    [BOM.csv]
2020-02-03 Start writing firmware
    [jlink-swd.cfg]
2020-02-03 firmware: Initialize tubes
2020-02-03 firmware: Listen to toggle pin interrupts
2020-02-03 schematics: Swap BTN_UP / BTN_DN netlabels
2020-02-03 firmware: Switch: Use periodic timer task, not EXTI
    Debouncing with a temporarily disabled interrupt works for the initial
    switch push, but when releasing the switch again, the interrupt may fire
    again.
    Due to that reason, switch to polling in a periodic timer task.
2020-02-03 firmware: Debounce toggle switch inputs
2020-02-03 hardware: Add tube anode resistor
    Refs #19
2020-02-25 Update libraries, re-route nixie tubes
    Fixes #19
2020-02-25 Generate v1.1 fabrication data
    [BOM.csv, Nixie_Counter_BOM.csv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]
2020-03-10 firmware: Show numbers >= 10 on tubes
2020-06-20 Switch from RTFM to RTIC (#29)
    Just a rename and a bump of the Rust version to 1.41
2022-10-13 Upgrade debouncr, switch to stateful debouncing
2022-10-13 Upgrade stm32f1xx-hal to 0.6
2022-10-13 Upgrade stm32f1xx-hal to 0.7
2022-10-13 Upgrade stm32f1xx-hal to 0.8 and rtic to 1.0
2022-10-13 Upgrade stm32f1xx-hal to 0.9
2022-10-15 Fix button poll interval
    [main.rs]
2022-10-17 Add enclosure SVG
2023-10-16 Create socket
2023-10-16 Fix timer resolution
    The timers in the blue pill are 16bit timers. When used with µs
    resolution, they cannot cover the timespans needed to wait for the
    sending of a request, for example.
    Instead, use millisecond precision. This should be sufficient for ATAT /
    esp-at-nal.
    [main.rs]
2023-10-16 Add additional dispatcher interrupt
2023-10-16 Show errors in defmt
    [main.rs]
2023-10-16 Replace create_socket task with ensure_socket function
    [main.rs]
2024-10-27 Finish routing new board
2024-10-27 Re-layout schematic
2024-10-27 Add more notes to schematics
2024-10-27 Set up new firmware project with esp-idf-hal
    [jlink-swd.cfg]
2024-10-27 firmware: Read button, toggle red LED
2024-10-29 Control nixie tubes
2024-10-29 Enable WiFi LED after connection
2024-11-03 board: Add some stitching vias, adjust text positions
2024-11-03 Update README for ESP32
2024-11-03 Add output files for v2.0
    [Nixie_Counter_COPPER-BOTTOM.gbr, Nixie_Counter_COPPER-TOP.gbr, Nixie_Counter_DRILLS-NPTH.drl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]
2024-11-17 firmware: Don't toggle LED with button
2024-11-17 firmware: Actually show count on nixie tubes
2024-12-01 Start switch from esp-idf-hal to esp-hal with embassy
2024-12-15 Don't crash when sending request without connection
    [main.rs]
2024-12-15 Blink while establishing WiFi connection
    This is implemented by moving the WiFi LED control to a dedicated task.
    The task can receive commands over an async channel in order to turn on
    or off the LED, or blink it.
2024-12-21 PCB: Add thermal relief to ground planes
2024-12-22 PCB: Update library elements
2024-12-23 PCB: Select some part numbers
2025-01-06 Firmware: Increase max DNS servers to 4
    This fixes a panic at Coredump 😄
2025-01-16 Add more assembly information
2025-01-16 Add BOM
    [Nixie_Counter_v2.0_BOM_Std.csv]
